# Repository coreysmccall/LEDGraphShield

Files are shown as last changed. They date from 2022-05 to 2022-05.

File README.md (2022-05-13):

This is an Arduino shield design and corresponding library for the Siemens RBG-8820 and Siemens RBG-112 LED bar graph modules.

# LEDGraphShield
The LED Graph Shield is useful for visualizing a high-resolution numerical value or any other data that can be described by a single row of 100 LEDs. The included Arduino software library with code examples makes it easy to get started with either the red or red/yellow bar graph module.

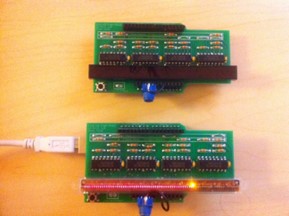
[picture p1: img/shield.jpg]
Shield Image

<center>The LED Graph Shield after assembly with the red (top) and red/yellow (bottom) modules. The center pin of the blue potentiometer is connected to analog input pin A0 for the example code.</center>

## Assembling the Shield
Assemble the shield by first soldering male headers to the bottom of the outside I/O pins and female headers to top of the inside I/O pins. It may be easiest to solder the male headers first while they are mounted into the I/O headers of an Arduino. Next, solder 220Ω resistors into the third and fourth rows of resistor marks, and 0.1µF capacitors into the capacitor marks. Next, solder the four 74HC595 shift registers into the IC marks. And finally, solder the bar graph module or a long female header into the 38-pin mark. The module should be set such that the end with the group of 3 pins is on the right, and the left most pin is in the left most mounting hole.

The LED Graph Shield is compatible with both the red (Siemens RBG-8820) and red/yellow (Siemens RBG-112) bar graph modules. To configure the shield for either module, follow the instructions printed on the face of the board. For the red module, wire resistors to the marks in the first row of resistor marks, short the resistor marks in the second row, and short the square jumper mark at the bottom of the board. For the red/yellow module, just wire resistors to the marks in the second row, and short the resistor marks in the first row. 

## Loading the Software Library
Copy the LEDGraphShield folder to your Arduino install directory. Once the library is installed, the examples can be run from the File->Examples->LEDGraphShield menu within the Arduino IDE.

To use the library, include LEDGraphShield.h, and instantiate a LEDGraphShield object by calling `LEDGraphShield(module_code)`. For the red module, set `module_code` to `R_MODULE`, and for the red/yellow module, set `module_code` to `RY_MODULE`. The following table gives summary of the functions available to each LEDGraphShield instance.

| Name 	 					  | Inputs	 													| Description  																|
| :---  | :--- 													| :---  															|
|`set_bar(int loc)`  			 	  |`loc`: location of bar to activate 							|Sets which single bar to display on red segments			 			 	|
|`set_ybar(int loc)` 			 	  |`loc`: location of bar to activate 							 |Sets which single bar to display on yellow segments			 		|
|`set_bars(int loc, boolean value)` |`loc`: location of bar to select, value: value to set selected bar |Sets values in output buffer for red segments			 				|
|`set_ybars(int loc, boolean value)`|`loc`: location of bar to select, value: value to set selected bar |Sets values in output buffer for yellow segments			 			|
|`set_bars_cum(int loc)`			  |`loc`: maximum value on bar 								 	|Sets all bars up to a certain value in the output buffer for red segments  |
|`update_bar()`					  | 													 	|Refreshes single bar display			 								|
|`update_bars()`					  | 													 	|Refreshes multibar display from buffer			 						|

## Examples
### DisplayBar: Single Bar Display
To display a single bar, first run `set_bar()` with the corresponding bar location, and then `update_bar()` to update the display. When only a single bar is displayed, the display does not need to be constantly refreshed. 

The DisplayBar example displays the relative value read on the analog input pin A0 with a single bar segment.

### DisplayBars: Bar Graph Style Display
To display the output as a filled in bar instead of a single segment, `set_bars_cum()` and `update_bars(`) must be used instead of `set_bar()` and `update_bar()`. These functions allow more than one bar to be set at a time, however they require that update_bars() be constantly run in the main loop in order to keep the display refreshed.

The DisplayBars example displays the relative value read on the analog input pin A0 with a filled in bar of segments. If the red/yellow module is being used, the most recent peak of the input signal within the last second is shown using the yellow segments. 

### DisplayAnyBars: Arbitrary Bar Display
To display an arbitrary pattern on the module, use `set_bars()` to either turn on or off a particular segment. Once the segments have been set, remember to run `update_bars()` to refresh the display.

The DisplayAnyBars example displays the relative value read on the analog input pin A0 as a filled in bar that extends from the center. Before each call to `update_bars()`, a 100-iteration loop is run to set the value of each segment in order to create the correct shape.

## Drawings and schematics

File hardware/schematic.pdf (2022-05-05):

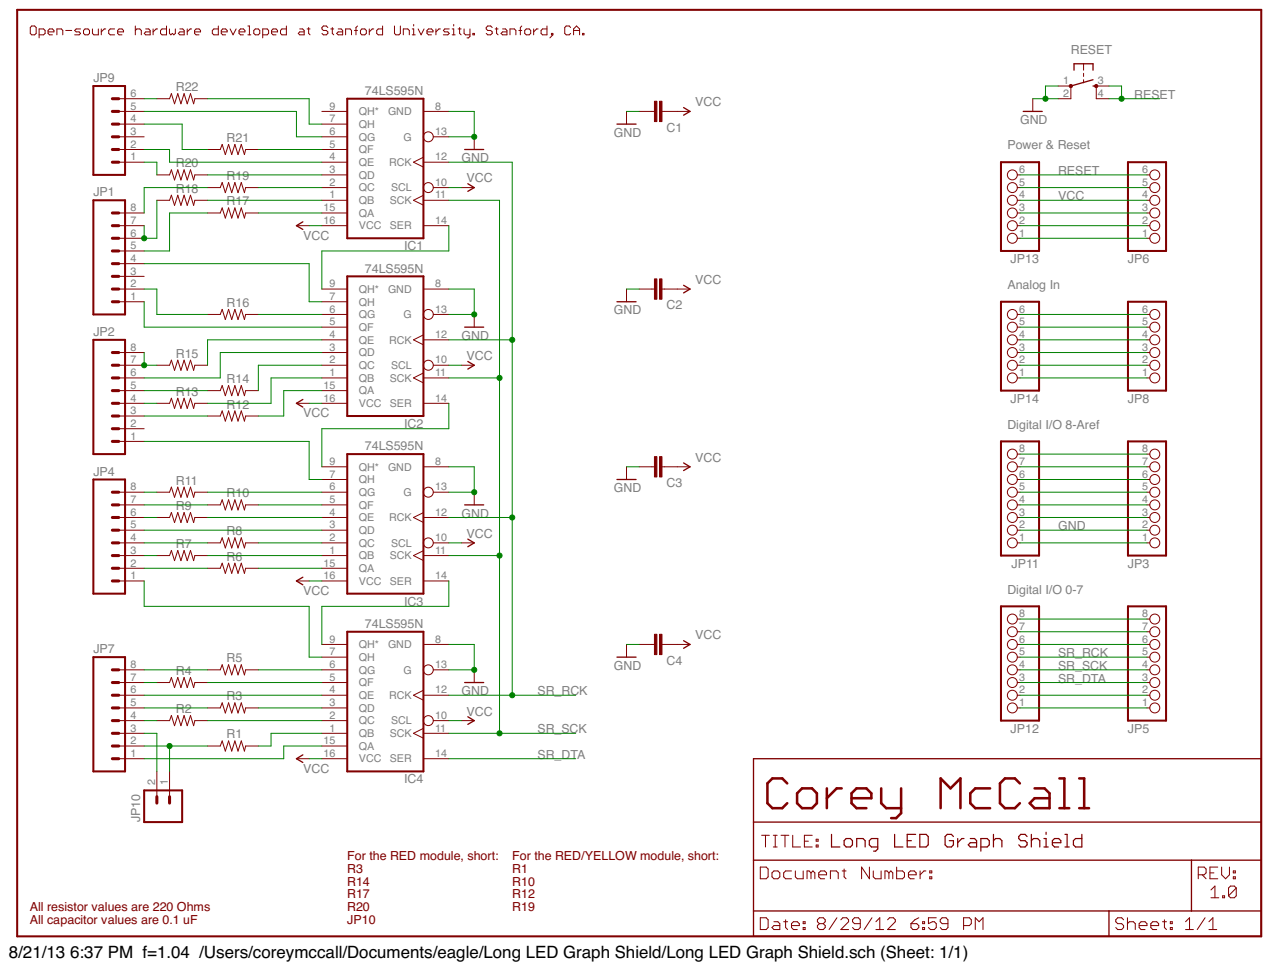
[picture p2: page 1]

For the RED module, short: For the RED/YELLOW module, short: R3

All resistor values are 220 Ohms All capacitor values are 0.1 uF

8/21/13 6:37 PM f=1.04 /Users/coreymccall/Documents/eagle/Long LED Graph Shield/Long LED Graph Shield.sch (Sheet: 1/1)

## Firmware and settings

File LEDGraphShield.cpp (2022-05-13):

/*
  LEDGraphShield - Library long LED bar graph matrix.
  Created by Corey McCall, November 9, 2011.
  Released into the public domain.
 
  
  Version: 1.0 (December 19, 2011), Original Code.
  Version: 1.1 (August 21, 2013), Arduino 1.0 Compatibility
*/ 


#include "LEDGraphShield.h"

/*
  Constructor
 
  _module values:
   1 -> R _module
   0 -> RY _module
*/
LEDGraphShield::LEDGraphShield(int module)
{
  //set pins for input (_DTA), shift reg clock (_SCK) and output latch clock (_RCK)
  _DTA=2; 
  pinMode(_DTA, OUTPUT);
  _SCK=3; 
  pinMode(_SCK, OUTPUT);
  _RCK=4; 
  pinMode(_RCK, OUTPUT);
  
  //set global module select varable
  _module=module;

  //clear output buffers
  for (int i=0;i<100;i++)
    _bufferR[i]=0;
  for (int i=0;i<10;i++)
    _bufferY[i]=0;

  //maps socket number to shift register pins for each module according to 
  //reference sheet
  _pin_map[0]=_module?  9:31;
  _pin_map[1]=_module?  5:8;
  _pin_map[2]=_module? 25:27;
  _pin_map[3]=_module? 20:24;
  _pin_map[4]=_module?  1:5;
  _pin_map[5]=_module?  2:3;
  _pin_map[6]=_module? 29:9;
  _pin_map[7]=_module? 13:12;
  _pin_map[8]=_module? 16:0;
  _pin_map[9]=_module? 26:1;
  _pin_map[10]=_module? 0:4;
  _pin_map[11]=_module? 3:7;
  _pin_map[12]=_module? 7:11;
  _pin_map[13]=_module?11:13;
  _pin_map[14]=_module?15:15;
  _pin_map[15]=_module?18:19;
  _pin_map[16]=_module?21:21;
  _pin_map[17]=_module?24:23;
  _pin_map[18]=_module?27:26;
  _pin_map[19]=_module?30:28;
  _pin_map[20]=_module? 4:30;
  _pin_map[21]=_module? 4:2;
  _pin_map[22]=_module? 4:6;
  _pin_map[23]=_module? 4:10;
  _pin_map[24]=_module? 4:14;
  _pin_map[25]=_module? 4:17;
  _pin_map[26]=_module? 4:20;
  _pin_map[27]=_module? 4:22;
  _pin_map[28]=_module? 4:25;
  _pin_map[29]=_module? 4:29;
  _pin_map[30]=_module? 4:18;
  _pin_map[31]=_module? 4:16;
}  

/*
  sets the red graph buffer to show a single bar at location (loc)
*/
void LEDGraphShield::set_bar(int loc)
{
  _position=loc;
}

/*
  sets the yellow graph buffer to show a single bar at location (loc)
*/
void LEDGraphShield::set_ybar(int loc){
  for (int i=0;i<10;i++)
    _bufferY[i]=(loc==i);
}

/*
  sets a single bar in the red graph buffer according to the (loc,value) pair
*/
void LEDGraphShield::set_bars(int loc, boolean value){
  _bufferR[loc]=value;
}

/*
  sets a single bar in the yellow graph buffer according to the (loc,value) pair
*/
void LEDGraphShield::set_ybars(int loc, boolean value){
  _bufferY[loc]=value;
}

/*
  sets the red graph buffer to show a single bar at location (loc)
*/
void LEDGraphShield::set_bars_cum(int loc){
  for(int i=0;i<100;i++)
    _bufferR[i]=(i<=loc); 
}

/*
  Updates the display to show a single bar value
*/
void LEDGraphShield::update_bar() {
  
  //fill first buffer bits with red anode
  for (int i=0;i<(_module?10:8);i++)
    _first_shift[i]=(i==(_position+(_module?0:4))%(_module?10:8));
  
  //fill second buffer bits with red cathode
  for (int i=0;i<(_module?10:13);i++)
    _first_shift[(_module?10:8)+i]=(i!=(_position+(_module?0:4))/(_module?10:8));

  //fill next buffer bits with yellow anode
  for (int i=0;i<(_module?0:10);i++)
    _first_shift[21+i]=_bufferY[i];

  //fill last buffer bit with yellow cathode
  if(!_module)
    _first_shift[31]=LOW;

  //refresh display from buffer
  update();
}

/*
  Updates the display to show multiple bar values
  This function must be constantly run to refresh the display.
*/
void LEDGraphShield::update_bars(){

  //for each common cathode set
  for (int i=0;i<(_module?10:13);i++){

    //fill first buffer bits with red anode
    for (int j=0;j<(_module?10:8);j++)
      _first_shift[j]=_bufferR[i*(_module?10:8)+j-(_module?0:4)];

    //fill second buffer bits with red cathode
    for (int j=0;j<(_module?10:13);j++)
      _first_shift[(_module?10:8)+j]= (j!=i);

    //fill next buffer bits with yellow anode
    for (int j=0;j<(_module?0:10);j++)
      _first_shift[21+j]=_bufferY[j];

    //fill last buffer bit with yellow cathode
    if(!_module)
      _first_shift[31]=LOW;
    update();
  }
}

/*
  writes data to shift register chain and refreshes display
*/
void LEDGraphShield::update(){
  //clear register output buffer
  for (int i=0;i<32;i++)
    _out_shift[i]=false;
    
  //fill register output buffer
  for (int i=0;i<32;i++)
    _out_shift[_pin_map[i]]=_first_shift[i];
  
  //pulse register output buffer into shift registers
  for (int i=31;i>=0;i--)
    pulse_data(_out_shift[i]);

  //refresh display by pulsing output latch.
  digitalWrite(_RCK,HIGH);
  digitalWrite(_RCK,LOW); 
}

/*
  inserts a single value into the shift register chain
*/
void LEDGraphShield::pulse_data(boolean value){
  digitalWrite(_DTA,value);
  digitalWrite(_SCK,HIGH);
  digitalWrite(_SCK,LOW); 
}

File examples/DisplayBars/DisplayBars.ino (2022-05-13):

/*
  DisplayBars
 This example displays a row of LEDs according to 
 the value of analog pin 0. Notice that when multiple
 LEDs are lit, the display needs to be constantly
 refreshed. For the RY module, the peaks are also 
 shown in yellow.
 
 Created by Corey McCall, November 9, 2011.
 Released into the public domain.
 
 Updated: December 19, 2011.
 Version: 1.0
 */ 

#include <LEDGraphShield.h>

//use RY_MODULE for red/yellow module
//use R_MODULE for red module
LEDGraphShield L = LEDGraphShield(RY_MODULE);
const int IN_PIN = A0;

//map each yellow bar to a position on the red bar graph
const int ymap[10]={ 
  10, 20, 30, 40, 50, 60, 70, 80, 90, 99};

//current peak
int max_val=0;

//timeout timer
long timer=0;

void setup(){
  ;
}

void loop()
{
  //scale input value to 100 segment display
  int value=map(analogRead(IN_PIN),0,1023,0,99);

  //refresh peak
  if(millis()-timer > 1000){
    max_val=0;
    timer=millis();
  }
  if(value>max_val)
    max_val=value;
  set_peak(max_val);


  //update display (run this constantly to refresh display)
  L.set_bars_cum(value);
  L.update_bars();
}

//This function sets the 
void set_peak(int peak){
  for (int i=0;i<10;i++)
    if(peak >= ymap[i])
      L.set_ybar(i);
  if(peak<ymap[0])
    L.set_ybar(-1);
}
